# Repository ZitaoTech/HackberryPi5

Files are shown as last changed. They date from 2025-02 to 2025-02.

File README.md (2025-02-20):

# HackberryPi5
A handheld Linux device using Raspberry Pi5 as Core with 4" 720X720 TFT Touch display and the original blackberry keyboard. With the feature of raspberry pi 5 you can build up to 16+512GB cyberdeck beast yourself!  





### [Questions or need more info? Join my Discord Channel!](https://discord.gg/WzPthAmMbP)  
# <a name='About this handheld  '>About this handheld</a>

Here are some **Main Features:**  
**Main Processor**: Only compatible with Raspberry Pi5.  
**Display**: 4" 720X720 high resolution TFT display with multi-touch function.  
**Battery Type**: 2X18650 batteries  
**Battery Life**: If using with 2x3000mah 18650 batteries, this device can run up to 3-4 hours without charging.  
**Keyboard Mouse Combo**: Yes, this cyberdeck has keyboard and mouse combo on board. You can choose blackberry Q10 or Q20 or 9900 keyboard.  
**Fully customizable keymap**: You can connect the keyboard with a computer and customizable the keymap through [VIAL](https://get.vial.today/) easily.  
**Charging Ampere**: Charge through the Type-C port. 2A charging rate; this handheld can be fully charged within 3-4 hours.  
**Stemma I2C Port**: This device has a Stemma I2C port on board, you can connect with any I2C sensors.  
**Stereo  speakers on board**: This device is integrated with [bluetooth speakers](https://github.com/ZitaoTech/HackberryPi5/tree/main/Sound) on board, you can connect with it to make sound.  

# <a name='Different Operating System  '>Different Operating System</a>
You can install Kali, Raspberrypi OS, or Retropi and many other OS into HackberryPi.  
[This page](https://github.com/ZitaoTech/HackberryPi5/tree/main/Screen) will tell you how to install the display driver in a different operating system.  

# <a name='Dimension and Weight  '>Dimension and Weight</a>
Dimension of HackberryPi: 91.8x143.5x27.5mm  
Weight without battery: 252 Gram  
Weight with battery: 342 Gram  



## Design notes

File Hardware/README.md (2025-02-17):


Ask me any questions if you want

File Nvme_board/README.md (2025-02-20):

# This device can work with ssd or AI accelerator card like Helio 8, here are the steps.

### 1. The nvme board is an accessory from [Waveshare](https://www.waveshare.com/pcie-to-m.2-board-e.htm), you need to buy it if you want to use the device with ssd.  



### 2. Not all 2242 or 2230 ssd can work with this nvme board, I suggest you just buy the ssd from [Waveshare](https://www.waveshare.com/sk-nvme-2242-128g-ssd-m.2.htm).  



### 3. The nvme board from waveshare can also work with the AI accelerator card like Helio 8. 



### One using tip: You can hide the cable under the ssd like this so that the cable won't disturb you in the case  



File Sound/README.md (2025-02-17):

# Make sound on HackberryPi5

Yes, HackberryPi5 has stereo speakers on board, you can connect to the speakers with via bluetooth. Here are the steps to enable the sound.

### 1. First enable bluetooth on the pi.

### 2. Search device, you can find a device called XWF-M18-M28-M38, pair with it


### 3. After you pair with it successfully, connect it


### 4. Make a reboot, otherwise you will likely not be able to adjust the volume as far as I know.

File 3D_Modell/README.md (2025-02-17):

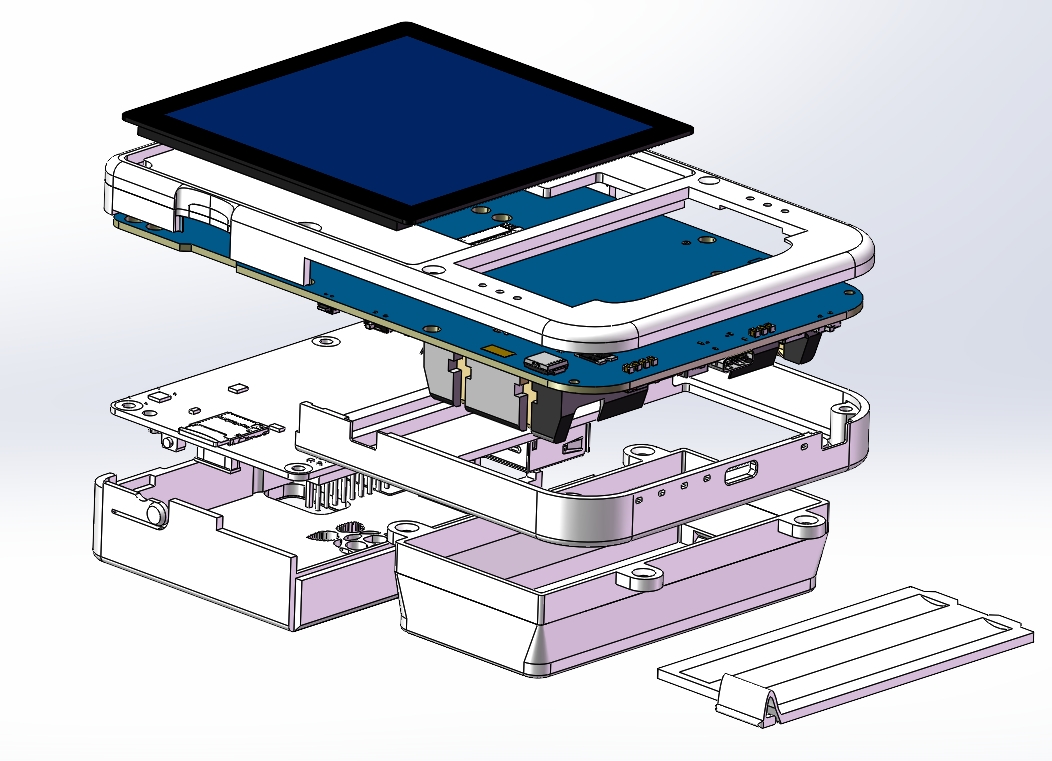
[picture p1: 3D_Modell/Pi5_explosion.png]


Insert Nut: 2 pcs M2x3x3  
Spacer: 4 pcs M2.5X15+6mm  
Screws: 4 pcs M2.5x6  
2pcs M2x6  
2pcs M2x14  

recommend to print the red switch with 0.2mm nozzel

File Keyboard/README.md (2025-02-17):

hackberrypi9900_vial.uf2: default firmware file for the keyboard controller chip(RP2040) on HackberryPi with BB9900 keyboard  
layout_hackberrypi_9900.vil: default keyboard layout setting file on VIAL for HackberryPi with BB9900 keyboard  

### How to use the .vil file?  
Let's say that you changed many keycodes and want to reset the keyboard layout  
First download vial app from [vial](https://get.vial.today/) homepage  
Install the vial app and open the app  
Then connect yor computer with Hackberry and in menu **file**->**Load saved layout** and select the .vil file, the keyboard layout will be reset.  

## Default Layout and Layers
### Layer0:
Keymap_Layer0

### Layer 1:
Keymap_Layer1

### Layer 2:
Keymap_Layer2

## Other Features
When holding Ctrl, mouse dpix2  
When holding Alt, mouse dpi/2  
When capslock, The trackpadbacklight will be turned on for Q10 version, and the backlight of the top row keys will be turned on for Q20 version. meanwhile the mouse will work as scroll wheel, you can browse a file quickly.  

The backlight of the keyboard will be turned off if you don't type anything for 30 seconds.

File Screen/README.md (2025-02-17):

# This page will tell you the ways to install the display driver in different operating system and some using tips of the display  
### First you need to install the operating system you need into RaspberryPi, this is the [tutorial](https://www.raspberrypi.com/documentation/computers/getting-started.html#installing-the-operating-system), when you choose device, select Raspberry Pi5.  
### There are 2 micro-HDMI ports on the top side of HackberryPi5. You can connect it with another screen. You can use the following commands to disable/enable the displaying.

```sh
vcgencmd display_power 0
vcgencmd display_power 1
```
### The default backlight brightness of the display after you turn HackberryPi on would be 100%. There is a physical button of the top side of HackberryPi. You can single press it to toggle the backlight of the display. You can also adjust the backlight brightness by long pressing the button: If you first long press the button the backlight brightness will slowly decrease to 10%, if you now release the button and long press the button again, the backlight brightness of the display will slowly increase to 100% again.  
# Raspberry Pi OS after 04/04/2022 or later  

Add the following line in `/boot/config.txt` in your TF card  

```sh
dtoverlay=vc4-kms-dpi-hyperpixel4sq
``` 
And the `config.txt` file will look like this:  
  
Follow the steps:  
Insert the TF card in to the slot  
Turn on the HackberryPi5, the screen will be black, the device will reboot several times until there is image on the display, if there isn't. Turn off the device and turn it on agin.  
And then your HackberryPi will run Raspberry Pi OS on the screen.  

# Raspberry Pi OS before 04/04/2022   

### Step 1  
Add the following lines in `/boot/config.txt` in your TF card  

```sh
dtoverlay=hyperpixel4
overscan_left=0
overscan_right=0 
overscan_top=0
overscan_bottom=0
framebuffer_width=720
enable_dpi_lcd=1
display_default_lcd=1
dpi_group=2
dpi_mode=87
dpi_output_format=0x5f026
dpi_timings=720 0 20 20 40 720 0 15 15 15 0 0 0 60 0 36720000 4
```
And the `config.txt` file will look like this:  


### Step 2  
Download the `hyperpixel4.dtbo`file in this github page   
Put the `hyperpixel4.dtbo`file into `/boot/overlays`folder  
Now you can insert the TF card in to the slot and your HackberryPi will run old RpiOs on the screen.  

# Other OS   
[Ubuntu](https://github.com/ZitaoTech/HackberryPi-4B/tree/main/Screen/Ubuntu)  
[Manjaro](https://github.com/ZitaoTech/HackberryPi-4B/tree/main/Screen/Manjaro)  
[Kali](https://github.com/ZitaoTech/HackberryPi-4B/tree/main/Screen/Kali%20Linux)  

# Troubleshoot  
  
You might found your display flickering or flashing like this on the picture. This happens when the display driver is powered but no image signal coming through.  
It can usually happen when you flash a new SD card or wake up from screen blanking.  
The display can recover itsself when you put the device running like 1 hour, but you need to disable screen blanking first.  
Here are steps you need to do to disable screen blanking:  
[On RaspberryPi OS](https://github.com/raspberrypi/documentation/blob/develop/documentation/asciidoc/computers/configuration/screensaver.adoc)  
[On Kali](https://superuser.com/questions/1185747/how-do-i-disable-the-screensaver-lock-in-kali-linux)

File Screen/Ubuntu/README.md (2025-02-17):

# Install Ubuntu on your HackberryPi5

After you flashe the Ubuntu image into the tf card, copy the following lines into `/boot/config.txt` and overwrite them.
Then you can see the HackberryPi now booting into Ubuntu

```sh
[all]
arm_64bit=1
kernel=vmlinuz
cmdline=cmdline.txt
initramfs initrd.img followkernel

# Enable the audio output, I2C and SPI interfaces on the GPIO header. As these
# parameters related to the base device-tree they must appear *before* any
# other dtoverlay= specification
dtparam=audio=on
#dtparam=i2c_arm=off
#dtparam=spi=off

# Comment out the following line if the edges of the desktop appear outside
# the edges of your display
disable_overscan=1

# If you have issues with audio, you may try uncommenting the following line
# which forces the HDMI output into HDMI mode instead of DVI (which doesn't
# support audio output)
#hdmi_drive=2

# Enable the KMS ("full" KMS) graphics overlay, leaving GPU memory as the
# default (the kernel is in control of graphics memory with full KMS)
dtoverlay=vc4-kms-v3d
disable_fw_kms_setup=1

# Autoload overlays for any recognized cameras or displays that are attached
# to the CSI/DSI ports. Please note this is for libcamera support, *not* for
# the legacy camera stack
camera_auto_detect=1
display_auto_detect=1

# Config settings specific to arm64
dtoverlay=dwc2

[pi4]
max_framebuffers=2
arm_boost=1

[pi3+]
# Use a smaller contiguous memory area, specifically on the 3A+ to avoid an
# OOM oops on boot. The 3B+ is also affected by this section, but it shouldn't
# cause any issues on that board
dtoverlay=vc4-kms-v3d,cma-128

[pi02]
# The Zero 2W is another 512MB board which is occasionally affected by the same
# OOM oops on boot.
dtoverlay=vc4-kms-v3d,cma-128

[cm4]
# Enable the USB2 outputs on the IO board (assuming your CM4 is plugged into
# such a board)
dtoverlay=dwc2,dr_mode=host

[all]
dtoverlay=vc4-kms-v3d
dtoverlay=vc4-kms-dpi-hyperpixel4sq
```
ac10a852343977e9eeb73fe11dc0dab

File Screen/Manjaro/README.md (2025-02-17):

# Install Manjaro on your HackberryPi5

First Download and flash the image from [Manjaro web](https://manjaro.org/products/download/arm?device=Raspberry+Pi+4B/400/3B%2B/3B/Zero+2)
Copy and paste the following lines into the `/boot/config.txt`  

```sh
dtoverlay=vc4-kms-v3d
dtoverlay=vc4-kms-dpi-hyperpixel4sq
```

Insert the TF card, and then you can see the HackberryPi now running Manjaro


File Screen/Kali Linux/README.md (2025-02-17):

# Install Kali on your HackberryPi5

You can download the image from [pi-imager](https://www.raspberrypi.com/software/)  
After you download and flash the image into the tf card, Copy and paste the following lines into the `/boot/config.txt`  

```sh
dtoverlay=vc4-kms-v3d
dtoverlay=vc4-kms-dpi-hyperpixel4sq
```

Insert the tf card and you can see HackberryPi running Kali linux


## Username and Password

Try 
```sh
kali
kali
```
Or
```sh
pi
pi
```

# Calibrate the Touchdisplay

Because desktop on Kali is running on x11, while other newer os lie RpiOS are updated to wayland, the touch can be handled differently on kali like the touch is inverted.
Follow the steps to do the calibration
Open a terminal and type
```sh
sudo nano /etc/X11/xorg.conf.d/40-libinput.conf
```
This should be an empty new file

Then type 
```sh
Section "InputClass"
Identifier "libinput touchscreen catchall"
MatchIsTouchscreen "on"
Option "CalibrationMatrix" "0 1 0 1 0 0 0 0 1"
MatchDevicePath "/dev/input/event**
Driver "libinput"
EndSection
```

Save and exit this file.  
Then reboot, then the touch is no more inverted.  
I suggest you do that under ssh, here is the way of [activating ssh on Kali](https://www.geeksforgeeks.org/how-to-enable-and-start-ssh-on-kali-linux/)

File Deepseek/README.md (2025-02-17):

# Running Deepseek on HackberryPi5  
Note: Ollama can only run with 64-bit OS, so make sure you have installed the 64-bit OS before you install ollama(step3)  

### 1. First update you operate-system  
```sh
sudo apt update
sudo apt upgrade
```

### 2. Ensure that the curl package is available on your Pi.  
```sh
sudo apt install curl
```

### 3. Install the Ollama software on your Pi 
```sh
curl -fsSL https://ollama.com/install.sh | sh
```

### 4. Running Deepseek on your HackberryPi5
```sh
ollama run deepseek-r1:1.5b
```


You can also try the 7b model, but that's kinda slow

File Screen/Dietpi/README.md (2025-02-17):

# Install DietPi on HackberryPi5  

DietPi is an extremely lightweight Debian OS, highly optimised for minimal CPU and RAM resource usage. The instruction is made by [Bjoern Franck](https://github.com/bjoernfranck)  
The tutorial for Pi4B and Pi5 is the same.  
You can view the tutorial at this [page](https://github.com/bjoernfranck/HackberryPi-4B/tree/main/DietPi)  


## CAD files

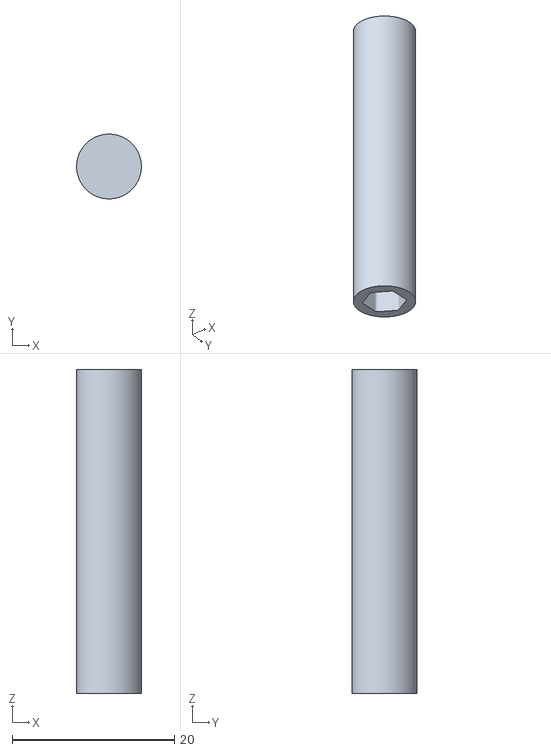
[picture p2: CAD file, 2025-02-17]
3D_Modell/HackberryPi5_white_tool.stl
8.00 x 8.00 x 40.0

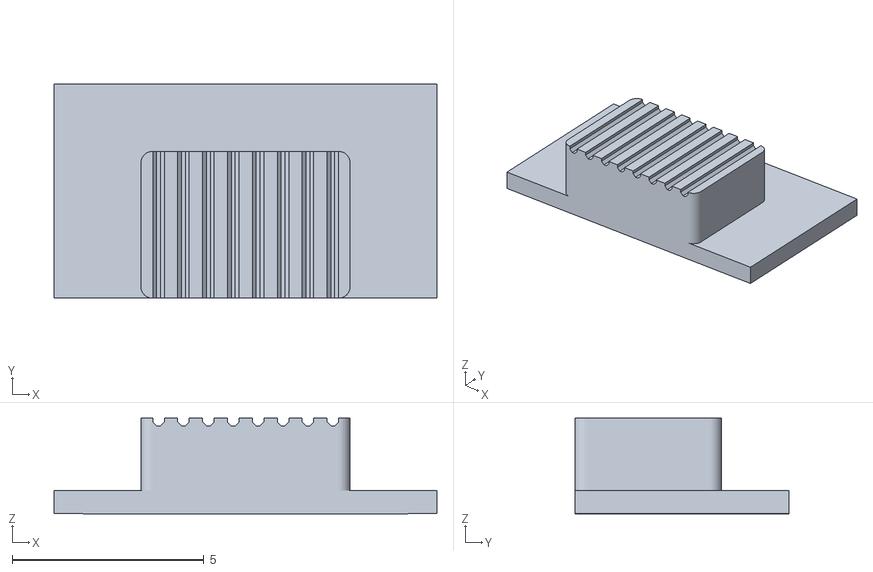
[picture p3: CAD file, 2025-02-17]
3D_Modell/HackberryPi5_red_switch.stl
10.0 x 5.60 x 2.49

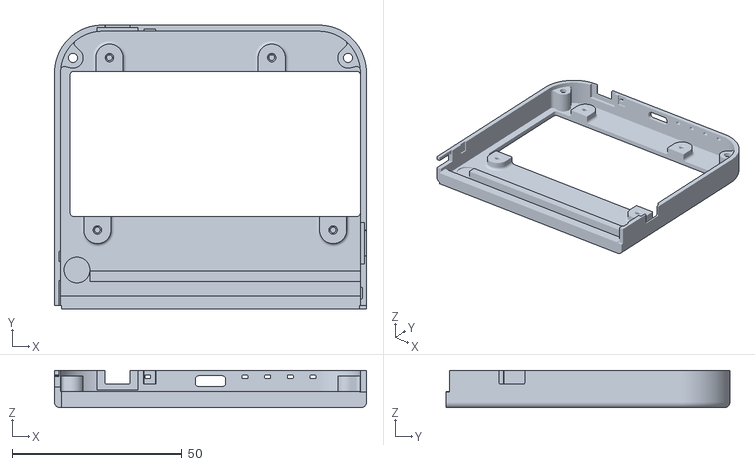
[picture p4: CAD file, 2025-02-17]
3D_Modell/HackberryPi5_lowercase.stl
91.8 x 83.5 x 11.0

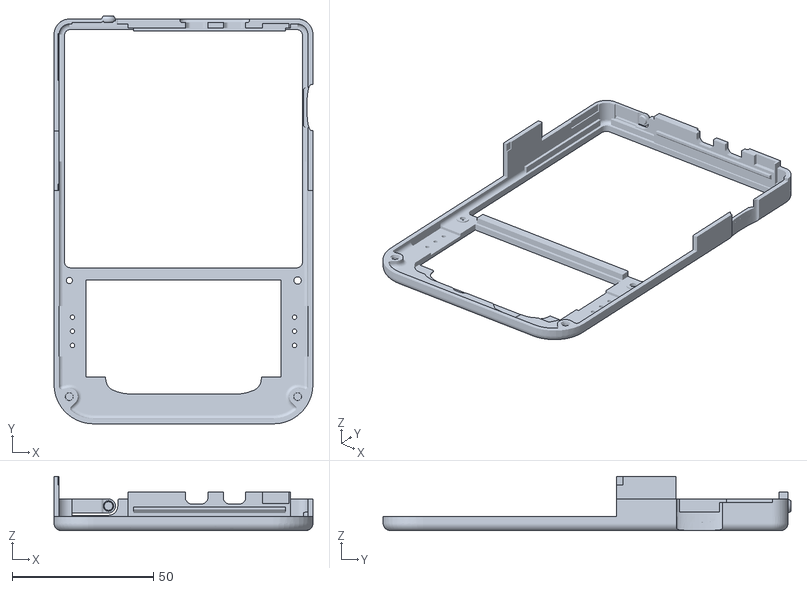
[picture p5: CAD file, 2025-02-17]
3D_Modell/HackberryPi5_Q20_uppercase.stl
91.8 x 144.5 x 19.2

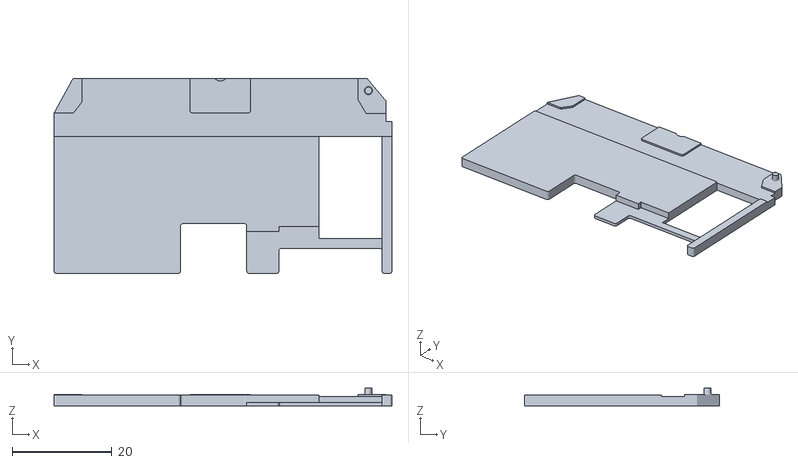
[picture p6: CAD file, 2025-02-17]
3D_Modell/HackberryPi5_Q20_Keyboardsupport.STL
67.8 x 39.1 x 3.60

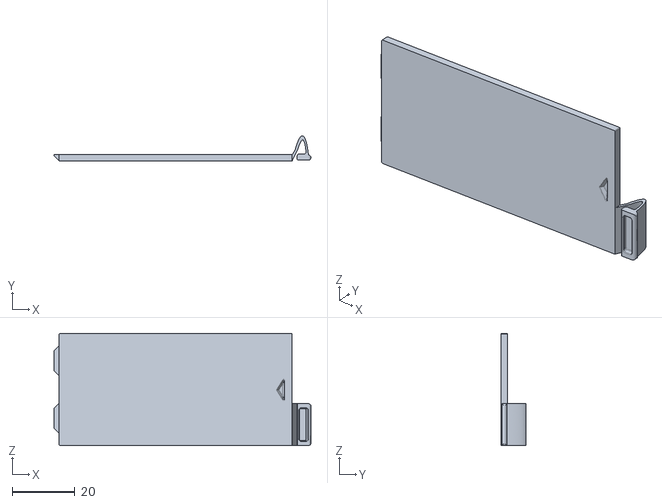
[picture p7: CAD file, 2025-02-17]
3D_Modell/HackberryPi5_batterycover.stl
82.2 x 8.14 x 35.9

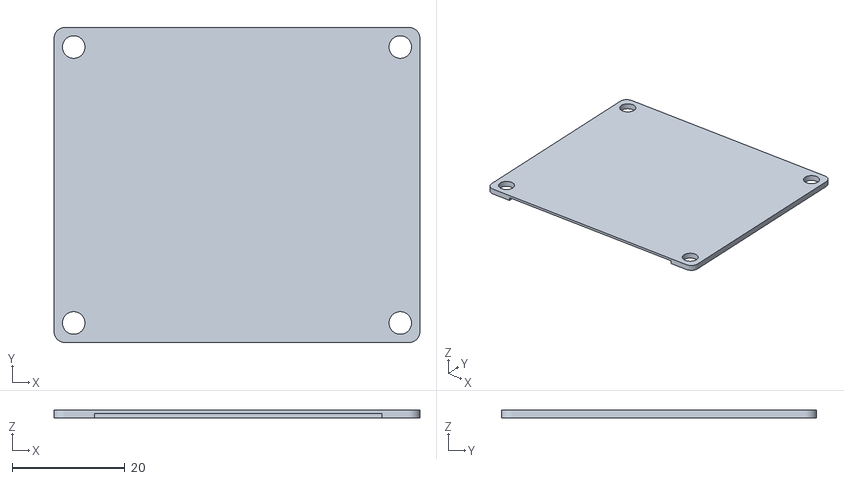
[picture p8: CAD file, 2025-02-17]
3D_Modell/HackberryPi5_Slot_protect.stl
65.0 x 56.0 x 1.40

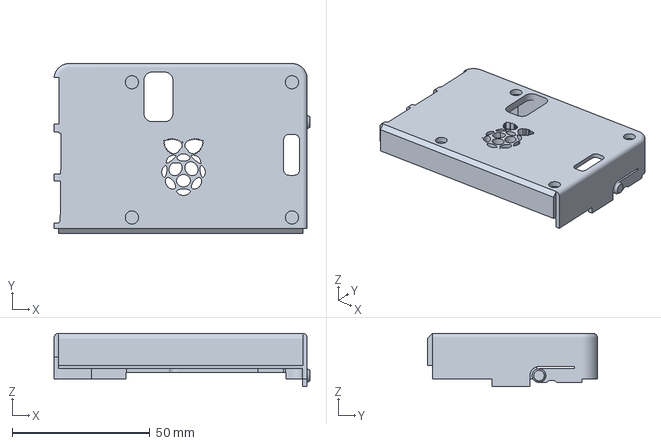
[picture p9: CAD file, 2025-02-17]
3D_Modell/HackberryPi5_Picase.3MF
92.8 x 61.6 x 19.3 mm

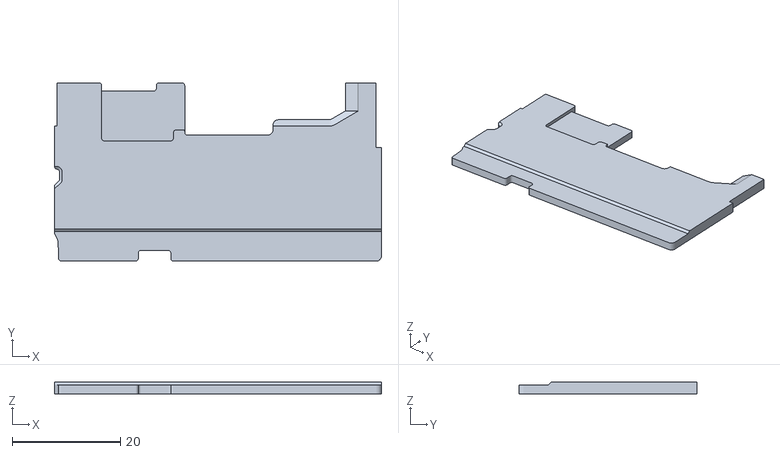
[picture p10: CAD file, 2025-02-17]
3D_Modell/HackberryPi5_9900_Keyboardsupport.STL
60.5 x 33.0 x 2.20

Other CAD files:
Mechanical_Drawing/HackberryPi5_mechanical drawing.dwg
3D_Modell/HackberryPi5_batterycase.stl
3D_Modell/HackberryPi5_9900_uppercase.stl
3D_Modell/HackberryPi5_Picase.stl

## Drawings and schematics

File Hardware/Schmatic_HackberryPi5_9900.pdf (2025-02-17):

# USB-C port

3V3 | pi 4B/5

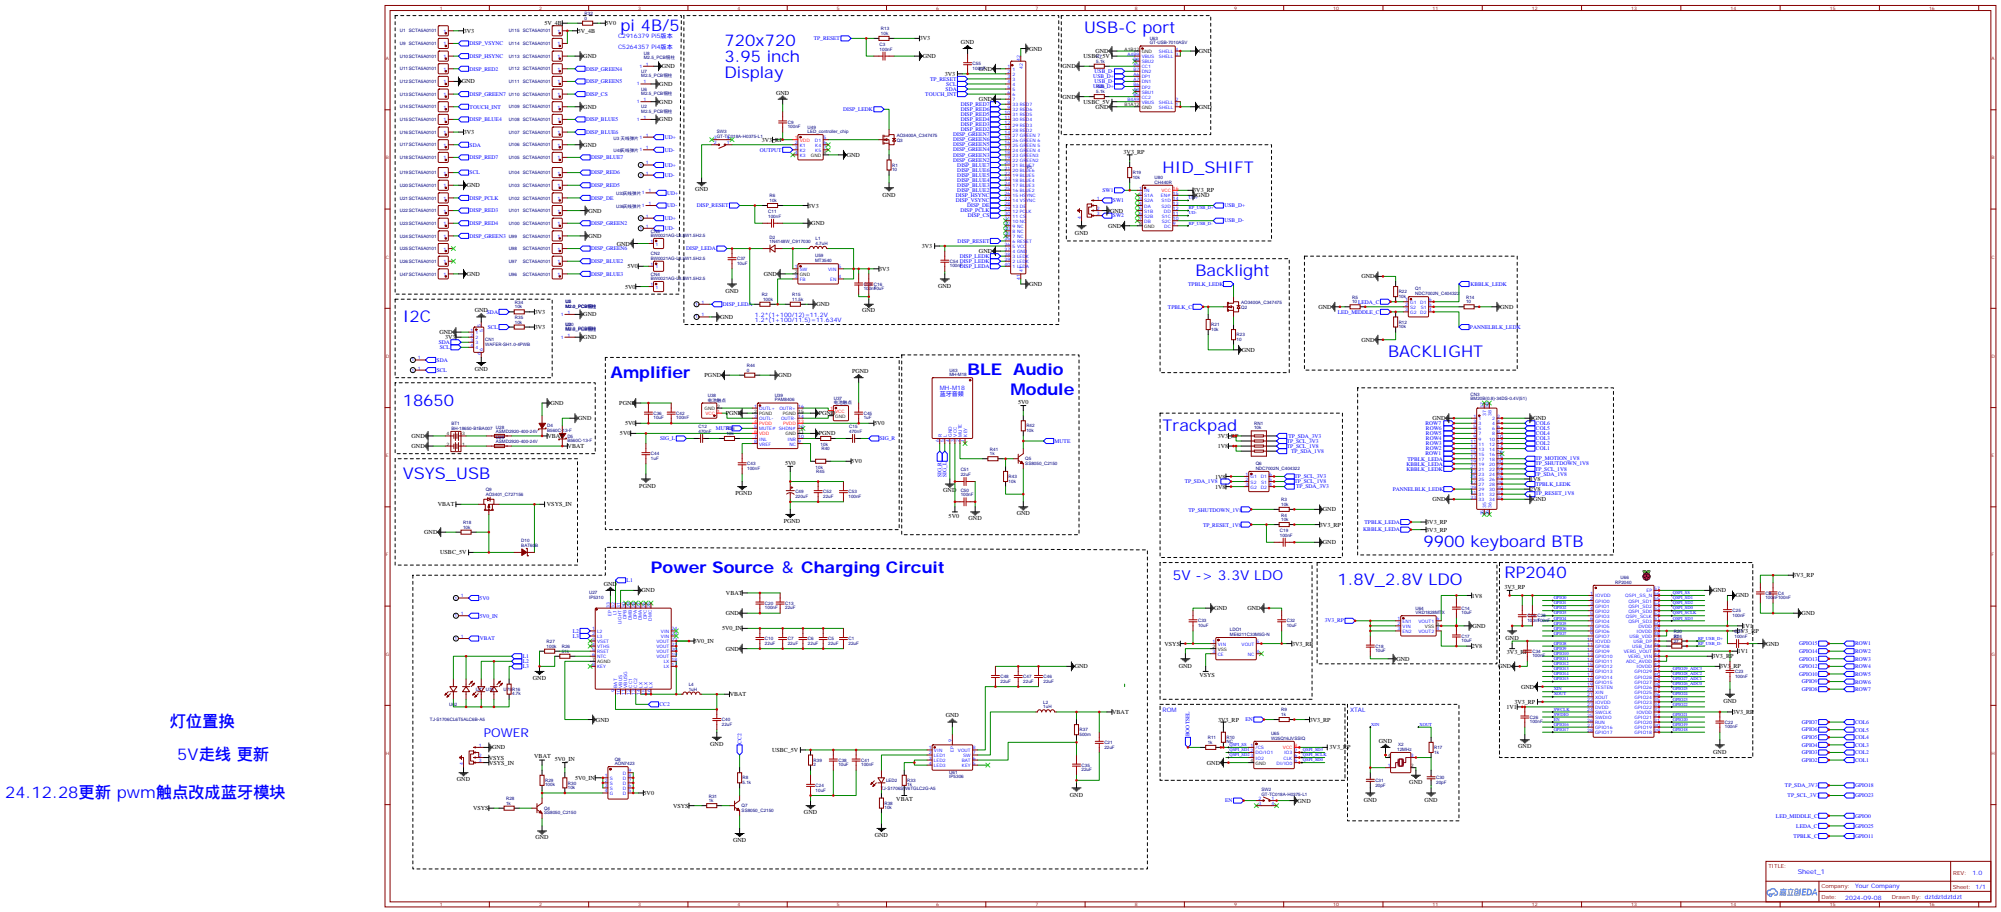
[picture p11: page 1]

Power Source ＆ Charging Circuit

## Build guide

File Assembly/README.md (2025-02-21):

# This page tells you how to install the pi5 into the device

### Note: If you put no batteries into the device, the pi draws power from the charging circuit which may can't provide enough current for the pi to boot because the peak current during booting is very high.
So you must put at least one 18650 battery into the device to make the device boot.  

PS： There is a tiktock video that introduces the [installation](https://www.tiktok.com/@h4ck1ng.me/video/7459517666387152150) of the pi

### 1. First remove the 4 black screws on the pi case with the bigger black screwdriver:  


### 2. Then, remove the 4 yellow spacer and the white protector with the white printed tool, I recommend tighening the two near the gpio slot first:  


### 3. Then, insert the pi5 with the 4 yellow spacer: 



### 4. Finally, tighten the pi case with the 4 black screws:  


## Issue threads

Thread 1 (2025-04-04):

batterycase.stl file is wrong

luqezr, 2025-04-04:
HackberryPi5_batterycase.stl is the same file as HackberryPi5_lowercase.stl (duplicated file with different name) and the actual batterycase stl file is not available to download
